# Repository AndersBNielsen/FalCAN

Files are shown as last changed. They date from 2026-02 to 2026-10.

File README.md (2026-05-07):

# FalCAN Probe

A compact USB 2.0 to CAN/RS‑485/RS‑422 hardware probe for interfacing and debugging CAN networks and differential serial buses. Designed in KiCad 9.
Firmware is here: <https://github.com/AndersBNielsen/FalCAN_fw>

## Can I buy one?
You can buy a FalCAN here: https://www.imania.dk/index.php?cPath=204&sort=5a&language=en

## Video overview
https://youtu.be/pHMQbOrLfP4

FalCAN on Youtube (https://www.youtube.com/watch?v=pHMQbOrLfP4)

## Blog post
https://abnielsen.com/falcan

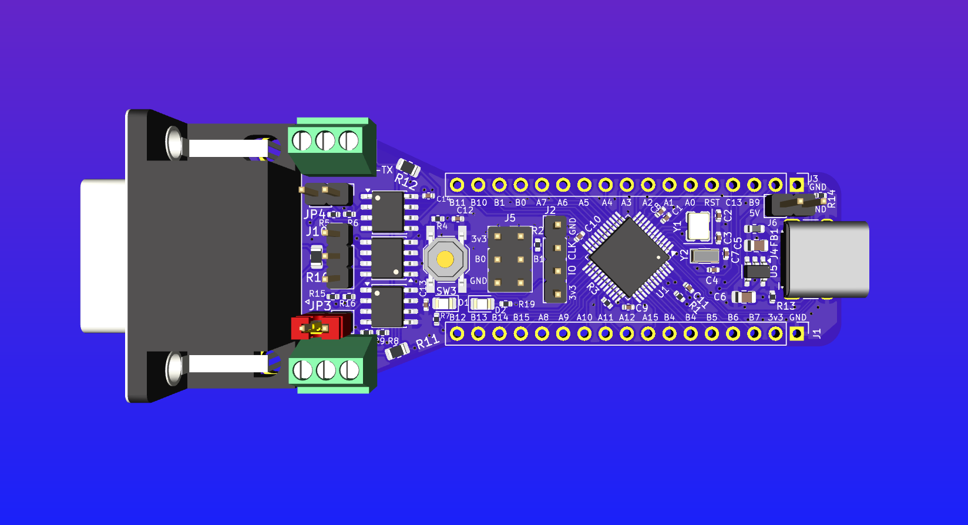
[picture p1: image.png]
FalCAN Probe


## Overview
- MCU: STM32F042C6Tx (USB FS device)
- CAN transceiver: SN65HVD230
- RS‑485/RS‑422 transceivers: SP3485EN (2x)
- USB‑C receptacle (HCTL HC‑TYPE‑C‑16P‑01A)
- 3.3V LDO regulator: MIC5504‑3.3
- Crystals: 8 MHz and 32.768 kHz
- CAN DE‑9 (female) connector for classic CAN pinout
- Jumpers/headers for boot, CAN, RS‑422/485 routing

Project metadata
- Title: FalCAN Probe
- Company: ABNielsen.com
- Revision: 0
- Board: 4‑layer FR4, ~1.6 mm 

## Repository Structure
- `USB-FalCAN.kicad_sch` — KiCad schematic
- `USB-FalCAN.kicad_pcb` — KiCad PCB layout
- `USB-FalCAN.kicad_pro` — KiCad project file
- `USB-FalCAN.kicad_prl` — KiCad project local settings
- `DSUB-9_... .kicad_mod` — Custom footprint for DE‑9 female connector
- `production/` — Fabrication outputs
  - `bom.csv` — Bill of Materials (includes LCSC part numbers)
  - `designators.csv` — Designator map
  - `positions.csv` — Pick‑and‑place (component positions)
  - `netlist.ipc` — IPC‑D‑356 netlist
  - `backups/` — Historical fabrication snapshots
- `fabrication-toolkit-options.json` — Fabrication/export options

## Key BOM Highlights
From `production/bom.csv`:
- MCU: STM32F042C6Tx (LQFP‑48)
- CAN: SN65HVD230 (SOIC‑8)
- RS‑485/422: SP3485EN (SOIC‑8, 2x)
- USB‑C receptacle: HC‑TYPE‑C‑16P‑01A
- LDO: MIC5504‑3.3
- Crystals: 8 MHz (3225), 32.768 kHz (3215)
- LEDs: Green (D1), Red (D2)
- DE‑9 CAN connector and various pin headers/jumpers

## Fabrication
- KiCad: generator version 9.0; board setup targets a 4‑layer FR4 stackup.
- Use KiCad’s Plot tool to generate Gerbers and drill files (settings are stored in the project). The IPC netlist in `production/netlist.ipc` can be provided to your manufacturer for electrical test.
- Pick‑and‑place: `production/positions.csv`.
- BOM: `production/bom.csv` contains LCSC part numbers to streamline sourcing; DNPs are excluded per `fabrication-toolkit-options.json`.

## Assembly & Bring‑Up
- Power from USB‑C (`VBUS`) with on‑board 3.3 V regulation.
- Boot/Programming: STM32F042 can be programmed via USB DFU or SWD (boot header present). Firmware will be released separately.
- CAN I/O: DE‑9 (male) with `CAN_H` and `CAN_L`; USB‑C provides data connection to host.
- RS‑485/RS‑422: Routing and driver enable/receive enable pins exposed via headers/jumpers.

If JP4 is closed at reset, USB is CDC USART1 for RS422/485.
If JP4 in open, USB is GS_USB CAN

Jumpers can be moved into any position after reset. 

RS-422: Default
Full duplex RS-422: Short JP3 & JP4

RS422/485 can be used in CAN mode using external USB-to-UART via USART1 pins (PB7 is RX and PB6 is TX)

## Status
Hardware files are provided; software/firmware will be licensed and released later.

## License
Hardware design files in this repository are licensed under the Creative Commons Attribution‑ShareAlike 4.0 International (CC BY‑SA 4.0). See `LICENSE-Hardware.md` for the full text.

Software/firmware (when added) will use a separate license.

## Credits
- Author/Company: ABNielsen.com
- EDA: KiCad 9

## Getting a PCB
This project is kindly sponsored by JLCPCB. They offer cheap, professional looking PCBs and super fast delivery.

Step 1: Get the gerber file zip package from the /hardware folder

Step 2: Upload to JLCPCB [https://jlcpcb.com/?from=Anders_N](https://jlcpcb.com/?from=Anders_N)

Upload

Step 3: Pick your color, surface finish and order.

Select settings

Save your choice

You can use these affiliate links to get a board for $2 and also get $123 worth of New User Coupons at: https://jlcpcb.com/?from=Anders_N

And in case you also want to order a 3D-printed case you can use this link. 
How to Get a $7 3D Printing Coupon: [https://3d.jlcpcb.com/?from=Anders3DP](https://jlc3dp.com/?from=Anders_N)

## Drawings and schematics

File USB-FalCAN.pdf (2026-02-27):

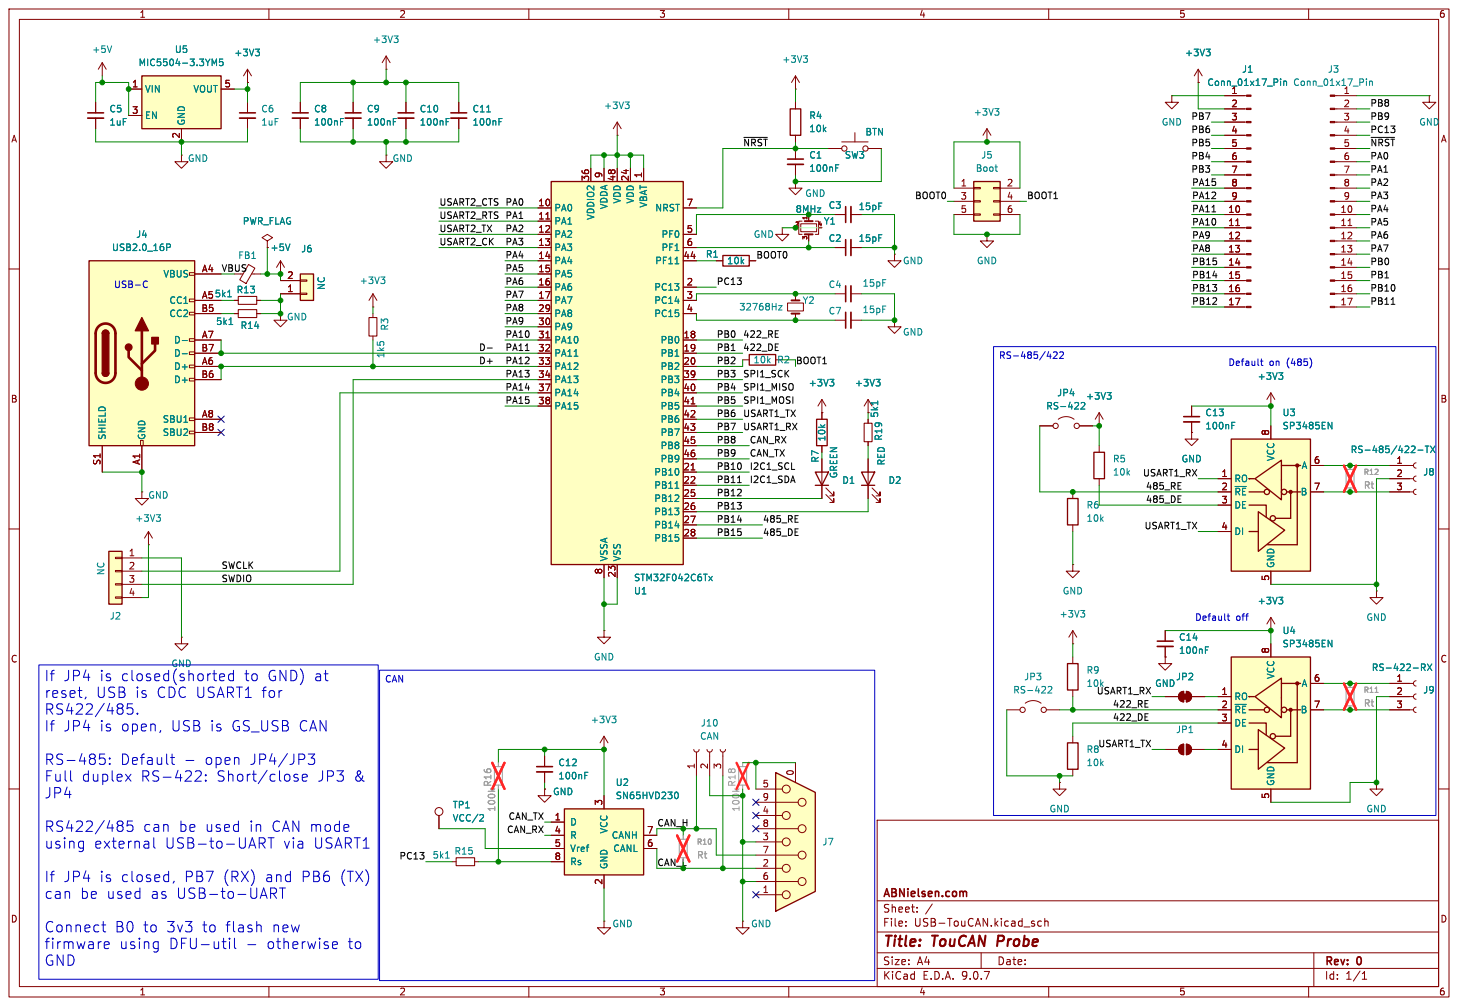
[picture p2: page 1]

1 VDD 24 VDD 48 VSS 23 VDDA
PA3 CAN_RX CAN_TX

reset, USB is CDC USART1 for
If JP4 is open, USB is GS_USB CAN

If JP4 is closed, PB7 (RX) and PB6 (TX) can be used as USB-to-UART

File: USB-TouCAN.kicad_sch Sheet: / ABNielsen.com

Connect B0 to 3v3 to flash new
GND

Id: 1/1 Title: TouCAN Probe

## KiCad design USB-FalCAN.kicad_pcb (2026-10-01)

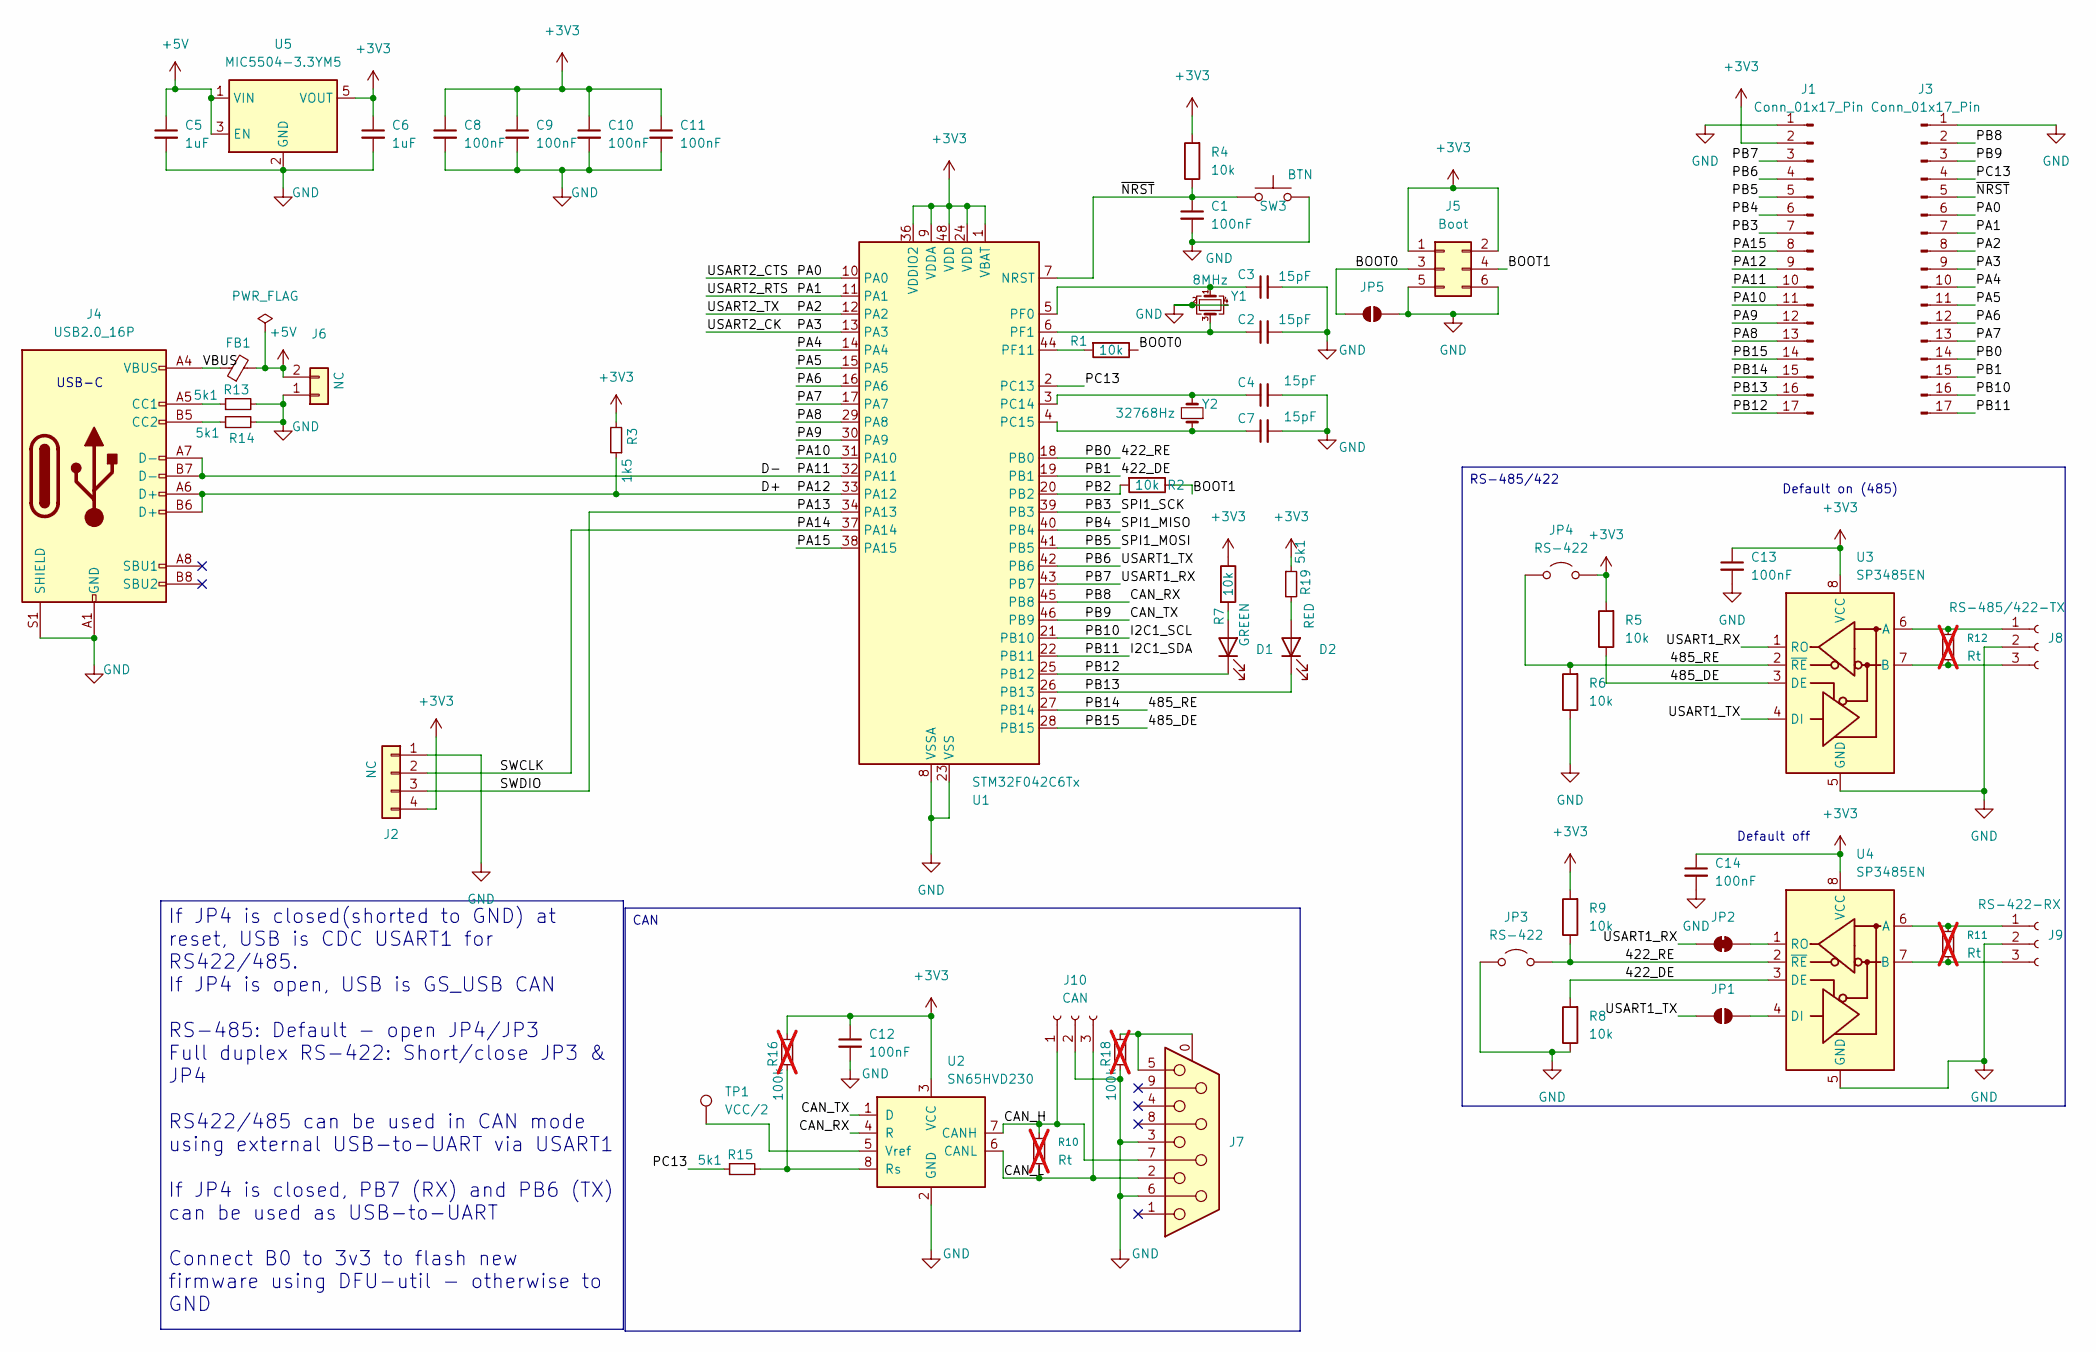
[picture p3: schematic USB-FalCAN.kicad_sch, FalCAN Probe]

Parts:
C1, C8, C9, C10, C11, C12, C13, C14: 100nF; C_0402_1005Metric; LCSC C307331
C2, C3, C4, C7: 15pF; C_0402_1005Metric; LCSC C1548
C5, C6: 1uF; C_0805_2012Metric; LCSC C28323
D1: GREEN; LED_0805_2012Metric; LCSC C2297
D2: RED; LED_0805_2012Metric; LCSC C84256
FB1: FerriteBead_Small; L_0603_1608Metric; LCSC C14709
J1, J3: Conn_01x17_Pin; PinHeader_1x17_P2.54mm_Vertical
J2: NC; PinHeader_1x04_P2.54mm_Vertical
J4: USB2.0_16P; USB_C_Receptacle_HCTL_HC-TYPE-C-16P-01A; LCSC C2894897
J5: Boot; PinHeader_2x03_P2.54mm_Vertical
J6: NC; PinHeader_1x02_P2.54mm_Vertical
J7: DE9_Receptacle; DSUB-9_Pins_Horizontal_P2.77x2.84mm_EdgePinOffset7.70mm_Hou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; LCSC C19077344
J8: RS-485/422-TX; PinHeader_1x03_P2.54mm_Vertical
J9: RS-422-RX; PinHeader_1x03_P2.54mm_Vertical
J10: CAN; PinHeader_1x03_P2.54mm_Vertical
JP1, JP5: SolderJumper_2_Open; SolderJumper-2_P1.3mm_Open_RoundedPad1.0x1.5mm
JP2: SolderJumper_2_Bridged; SolderJumper-2_P1.3mm_Bridged_RoundedPad1.0x1.5mm
JP3, JP4: RS-422; PinHeader_1x02_P2.54mm_Vertical
R1, R2, R4, R5, R6, R7, R8, R9: 10k; R_0402_1005Metric; LCSC C25744
R3: 1k5; R_0402_1005Metric; LCSC C25867
R10, R11, R12: Rt; R_0805_2012Metric; not fitted
R13, R14, R15, R19: 5k1; R_0402_1005Metric; LCSC C25905
R16, R18: 100k; R_0402_1005Metric; LCSC C25905; not fitted
SW3: BTN; SW_SPST_TL3342; LCSC C318884
TP1: VCC/2; TestPoint_Pad_D1.0mm
U1: STM32F042C6Tx; LQFP-48_7x7mm_P0.5mm; LCSC C88447
U2: SN65HVD230; SOIC-8_3.9x4.9mm_P1.27mm; LCSC C12084
U3, U4: SP3485EN; SOIC-8_3.9x4.9mm_P1.27mm; LCSC C8963
U5: MIC5504-3.3YM5; SOT-23-5; LCSC C3021093
Y1: 8MHz; Crystal_SMD_3225-4Pin_3.2x2.5mm; LCSC C5308002
Y2: 32768Hz; Crystal_SMD_3215-2Pin_3.2x1.5mm; LCSC C32346

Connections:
+3V3: C6.1, C8.1, C9.1, C10.1, C11.1, C12.1, C13.1, C14.1, J1.2, J2.4, J5.1, J5.2, JP4.2 (B), R3.2, R4.2, R5.2, R7.1, R9.2, R16.2, R19.1, U1.1 (VBAT), U1.9 (VDDA), U1.24 (VDD), U1.36 (VDDIO2), U1.48 (VDD), U2.3 (VCC), U3.8 (VCC), U4.8 (VCC), U5.5 (VOUT)
+5V: C5.1, FB1.2, J6.2, U5.1 (VIN), U5.3 (EN)
/422_DE: J3.15, R8.2, U1.19 (PB1), U4.3 (DE)
/422_RE: J3.14, JP3.2 (B), R9.1, U1.18 (PB0), U4.2 (~RE)
/485_DE: J1.14, R5.1, U1.28 (PB15), U3.3 (DE)
/485_RE: J1.15, JP4.1 (A), R6.2, U1.27 (PB14), U3.2 (~RE)
/BOOT0: J5.3, JP5.1 (A), R1.1
/BOOT1: J5.4, R2.1
/CAN_H: J7.7, J10.1, R10.1, U2.7 (CANH)
/CAN_L: J7.2, J10.3, R10.2, U2.6 (CANL)
/CAN_RX: J3.2, U1.45 (PB8), U2.4 (R)
/CAN_TX: J3.3, U1.46 (PB9), U2.1 (D)
/D+: J1.9, J4.A6 (D+), J4.B6 (D+), R3.1, U1.33 (PA12)
/D-: J1.10, J4.A7 (D-), J4.B7 (D-), U1.32 (PA11)
/I2C1_SCL: J3.16, U1.21 (PB10)
/I2C1_SDA: J3.17, U1.22 (PB11)
/PA0: J3.6, U1.10 (PA0)
/PA1: J3.7, U1.11 (PA1)
/PA2: J3.8, U1.12 (PA2)
/PA3: J3.9, U1.13 (PA3)
/PA4: J3.10, U1.14 (PA4)
/PA5: J3.11, U1.15 (PA5)
/PA6: J3.12, U1.16 (PA6)
/PA7: J3.13, U1.17 (PA7)
/PA8: J1.13, U1.29 (PA8)
/PA9: J1.12, U1.30 (PA9)
/PA10: J1.11, U1.31 (PA10)
/PA13: J2.3, U1.34 (PA13)
/PA14: J2.2, U1.37 (PA14)
/PA15: J1.8, U1.38 (PA15)
/PB2: R2.2, U1.20 (PB2)
/PB3: J1.7, U1.39 (PB3)
/PB4: J1.6, U1.40 (PB4)
/PB5: J1.5, U1.41 (PB5)
/PB6: J1.4, JP1.1 (A), U1.42 (PB6), U3.4 (DI)
/PB7: J1.3, JP2.1 (A), U1.43 (PB7), U3.1 (RO)
/PB12: D1.1 (K), J1.17, U1.25 (PB12)
/PB13: D2.1 (K), J1.16, U1.26 (PB13)
/PC13: J3.4, R15.1, U1.2 (PC13)
/VBUS: FB1.1, J4.A4 (VBUS), J4.A9 (VBUS), J4.B4 (VBUS), J4.B9 (VBUS)
/~NRST: C1.1, J3.5, R4.1, SW3.1, U1.7 (NRST)
GND: C1.2, C2.2, C3.2, C4.2, C5.2, C6.2, C7.2, C8.2, C9.2, C10.2, C11.2, C12.2, C13.2, C14.2, J1.1, J2.1, J3.1, J4.A1 (GND), J4.A12 (GND), J4.B1 (GND), J4.B12 (GND), J4.S1 (SHIELD), J5.5, J5.6, J6.1, J7.3, J7.6, J8.2, J9.2, J10.2, JP3.1 (A), JP5.2 (B), R6.1, R8.1, R13.2, R14.2, R18.1, SW3.2, U1.8 (VSSA), U1.23 (VSS), U1.35 (VSS), U1.47 (VSS), U2.2 (GND), U3.5 (GND), U4.5 (GND), U5.2 (GND), Y1.2, Y1.4
unnamed: D1.2 (A), R7.2
unnamed: D2.2 (A), R19.2
unnamed: J4.A5 (CC1), R13.1
unnamed: J4.B5 (CC2), R14.1
unnamed: J7.0 (PAD), J7.5, R18.2
unnamed: J8.1, R12.1, U3.6 (A)
unnamed: J8.3, R12.2, U3.7 (B)
unnamed: J9.1, R11.1, U4.6 (A)
unnamed: J9.3, R11.2, U4.7 (B)
unnamed: JP1.2 (B), U4.4 (DI)
unnamed: JP2.2 (B), U4.1 (RO)
unnamed: C4.1, U1.3 (PC14), Y2.2
unnamed: C7.1, U1.4 (PC15), Y2.1
unnamed: C3.1, U1.5 (PF0), Y1.1
unnamed: C2.1, U1.6 (PF1), Y1.3
unnamed: R1.2, U1.44 (PF11)
unnamed: R15.2, R16.1, U2.8 (Rs)
unnamed: TP1.1, U2.5 (Vref)

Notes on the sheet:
Default off
USB-C
Default on (485)
RS-485/422
CAN
If JP4 is closed(shorted to GND) at reset, USB is CDC USART1 for RS422/485. If JP4 is open, USB is GS_USB CAN RS-485: Default - open JP4/JP3 Full duplex RS-422: Short/close JP3 & JP4 RS422/485 can be used in CAN mode using external USB-to-UART via USART1 If JP4 is closed, PB7 (RX) and PB6 (TX) can 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

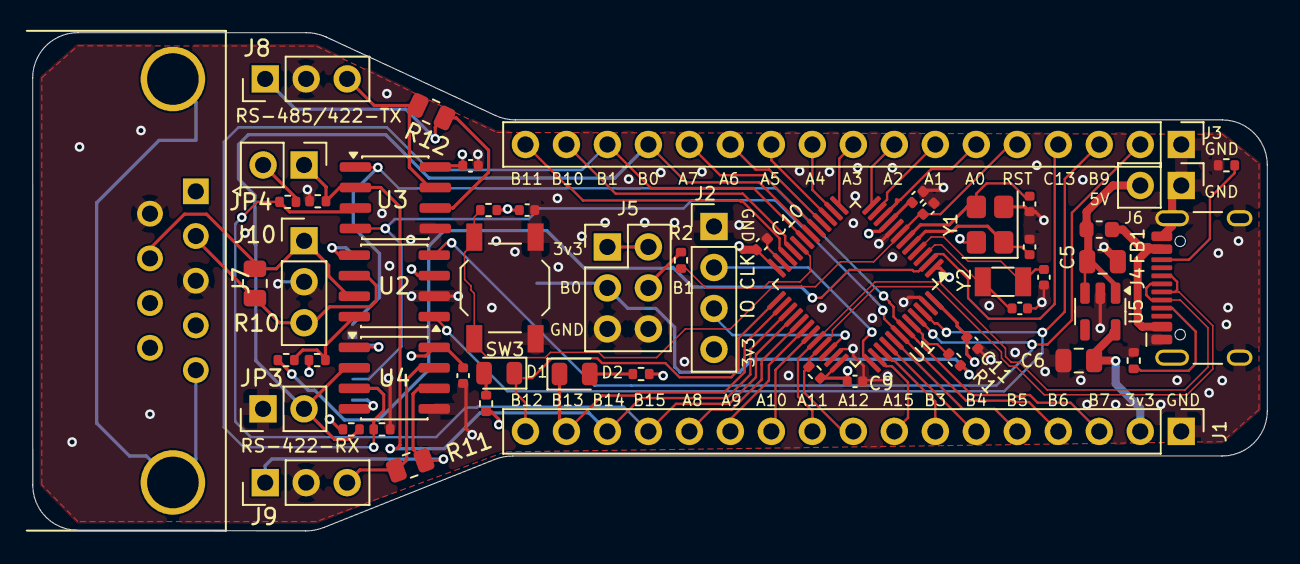
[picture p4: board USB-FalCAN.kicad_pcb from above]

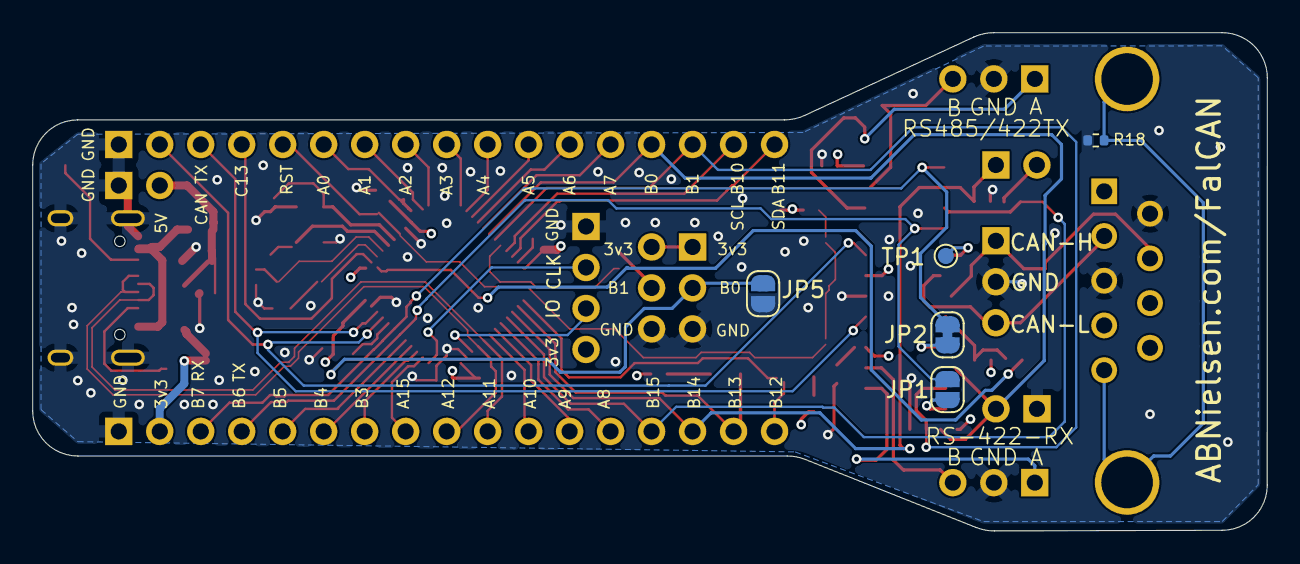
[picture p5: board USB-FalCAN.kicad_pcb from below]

Board: 4 copper layers, 76.5 x 30.9 mm, 59 parts (5 on the bottom side), 60 nets.

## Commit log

2026-02-01 Initial release
    [USB-TouCAN.kicad_pcb, USB-TouCAN.kicad_sch]
2026-02-04 Cleanup after PCB review
    [USB-TouCAN.kicad_pcb, USB-TouCAN.kicad_sch]
2026-02-27 Update schematic help text
    [USB-TouCAN.kicad_sch]
2026-04-06 Rename to FalCAN
    [USB-FalCAN.kicad_pcb, USB-FalCAN.kicad_sch]
2026-04-06 Replace USB-TouCAN files with USB-FalCAN
    [USB-FalCAN.kicad_pcb, USB-FalCAN.kicad_sch, USB-TouCAN.kicad_pcb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]
2026-04-09 Improve silk
    [USB-FalCAN.kicad_pcb, USB-FalCAN.kicad_sch]
2026-10-01 feat: Change to male D-sub, fix "B3" silk
    [USB-FalCAN.kicad_pcb, USB-FalCAN.kicad_sch]
